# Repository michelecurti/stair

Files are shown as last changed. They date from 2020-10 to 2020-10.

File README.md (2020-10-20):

# stair

Switch on a stair that for every step has a strip led, 
controlled in PWM.
All this to generate a stair "wave effect" for my sister.

## project structure

under hw there is the hardware
under fw there is the firmware

Meh..

## software requirements

I worked on OpenBSD.

For the hardware I used Kicad, for the firmware, vim + Makefile..

The toolchain is arm-none-eabi-gcc-linaro.

The "core" is the STM32 BluePill, some shift registers and some
mosfets..

To debug the board I used the st-link with openocd.

## how to compile

$ cd fw/stair/
$ make

## how to debug

$ make debug

## image

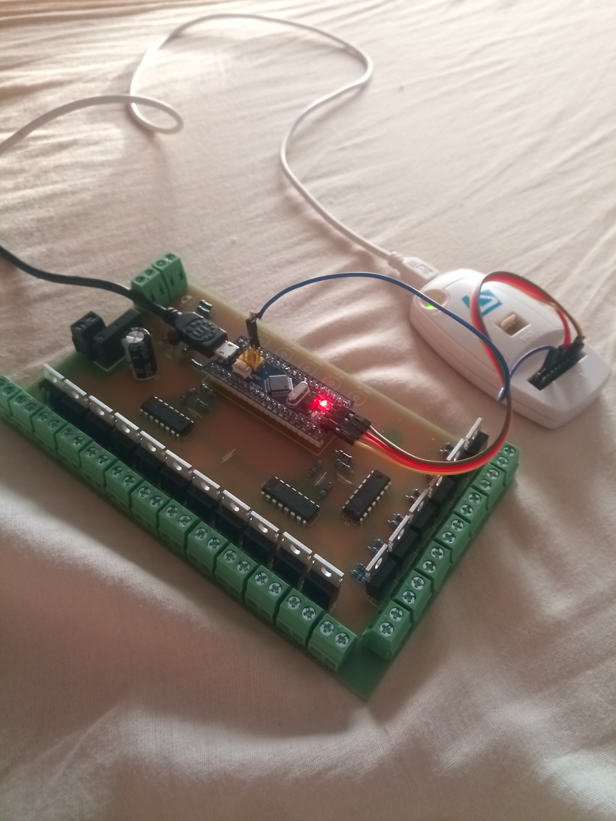
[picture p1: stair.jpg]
the board


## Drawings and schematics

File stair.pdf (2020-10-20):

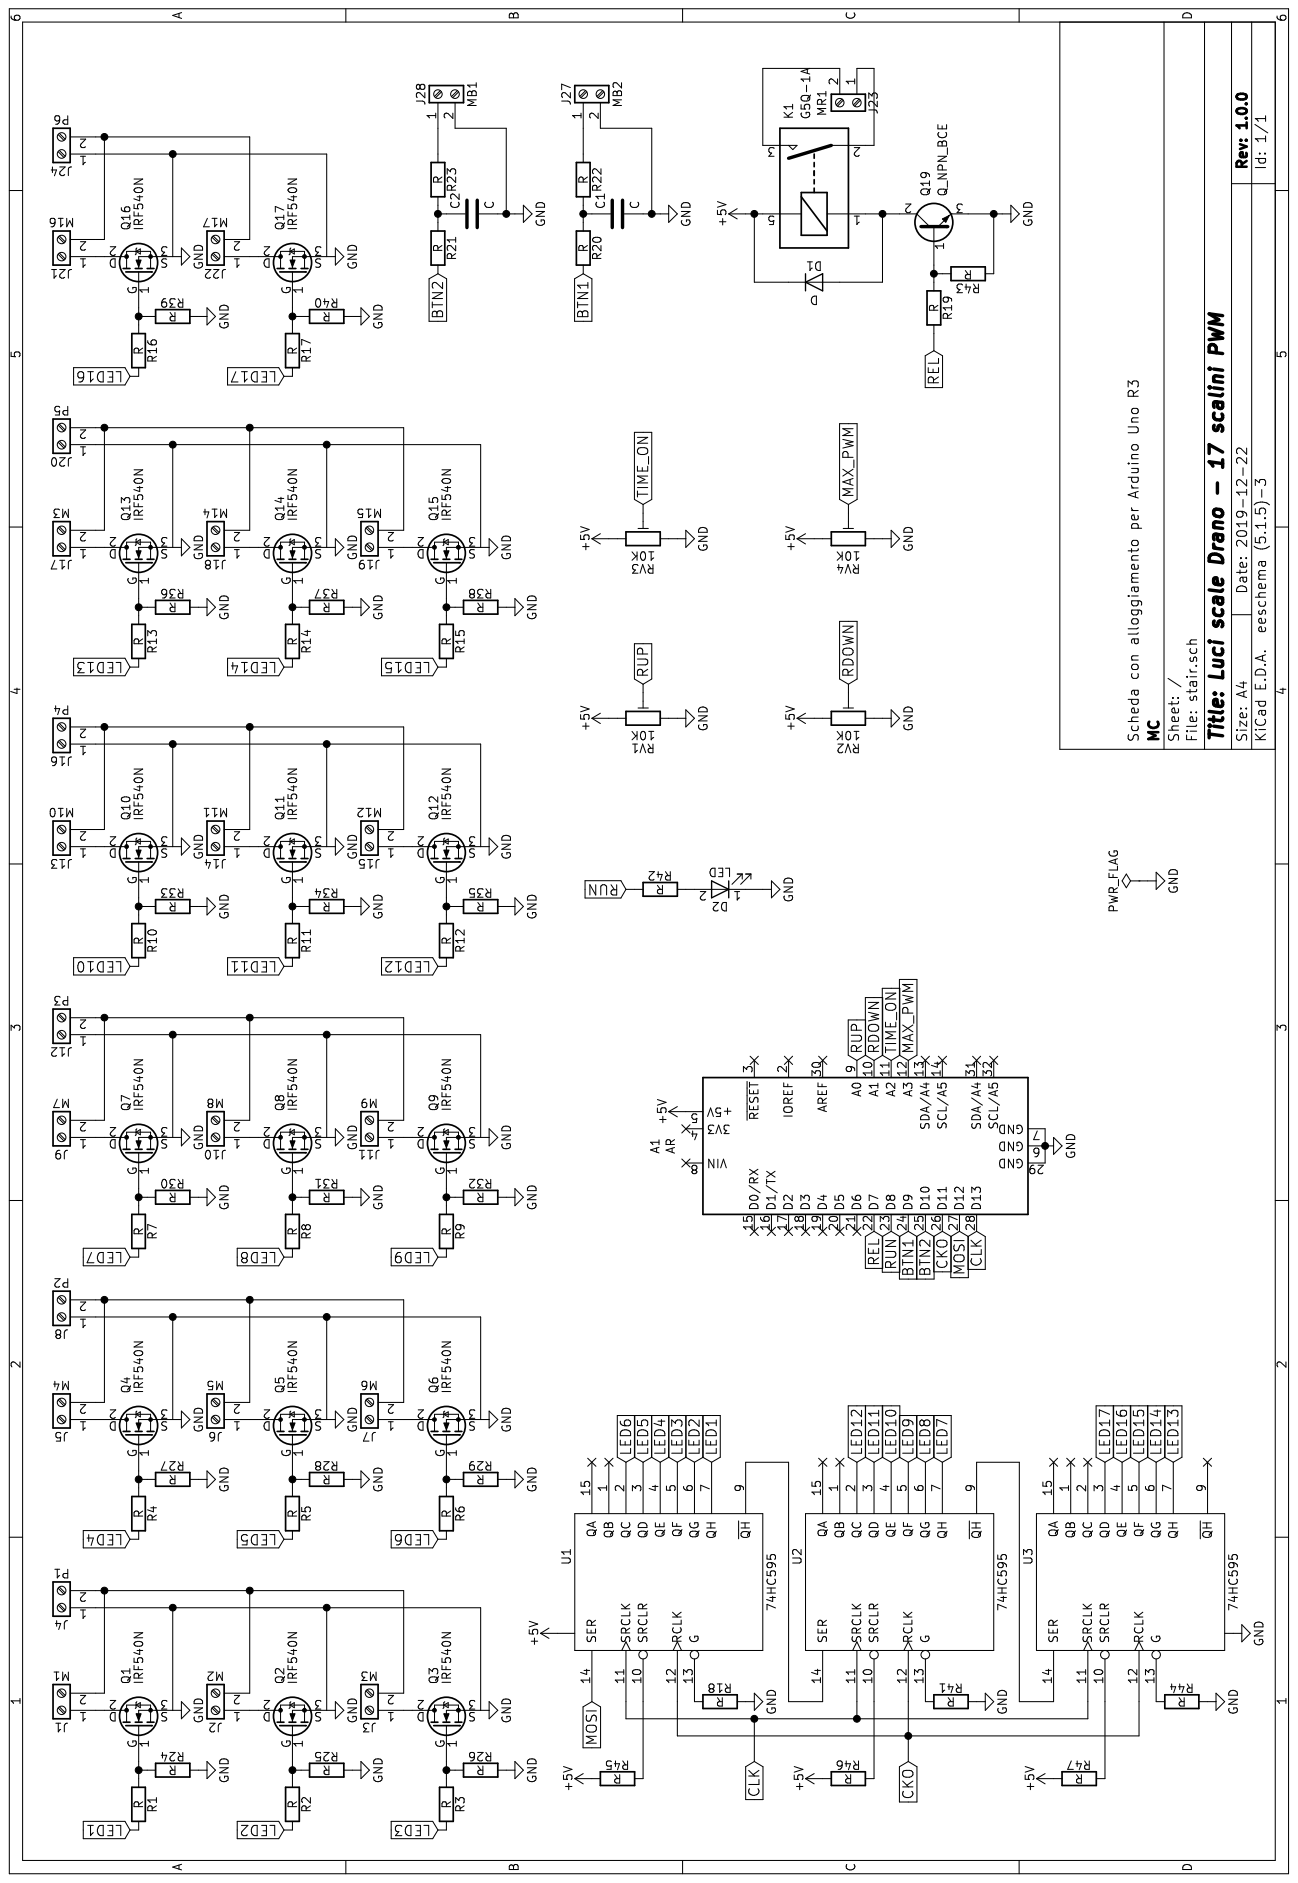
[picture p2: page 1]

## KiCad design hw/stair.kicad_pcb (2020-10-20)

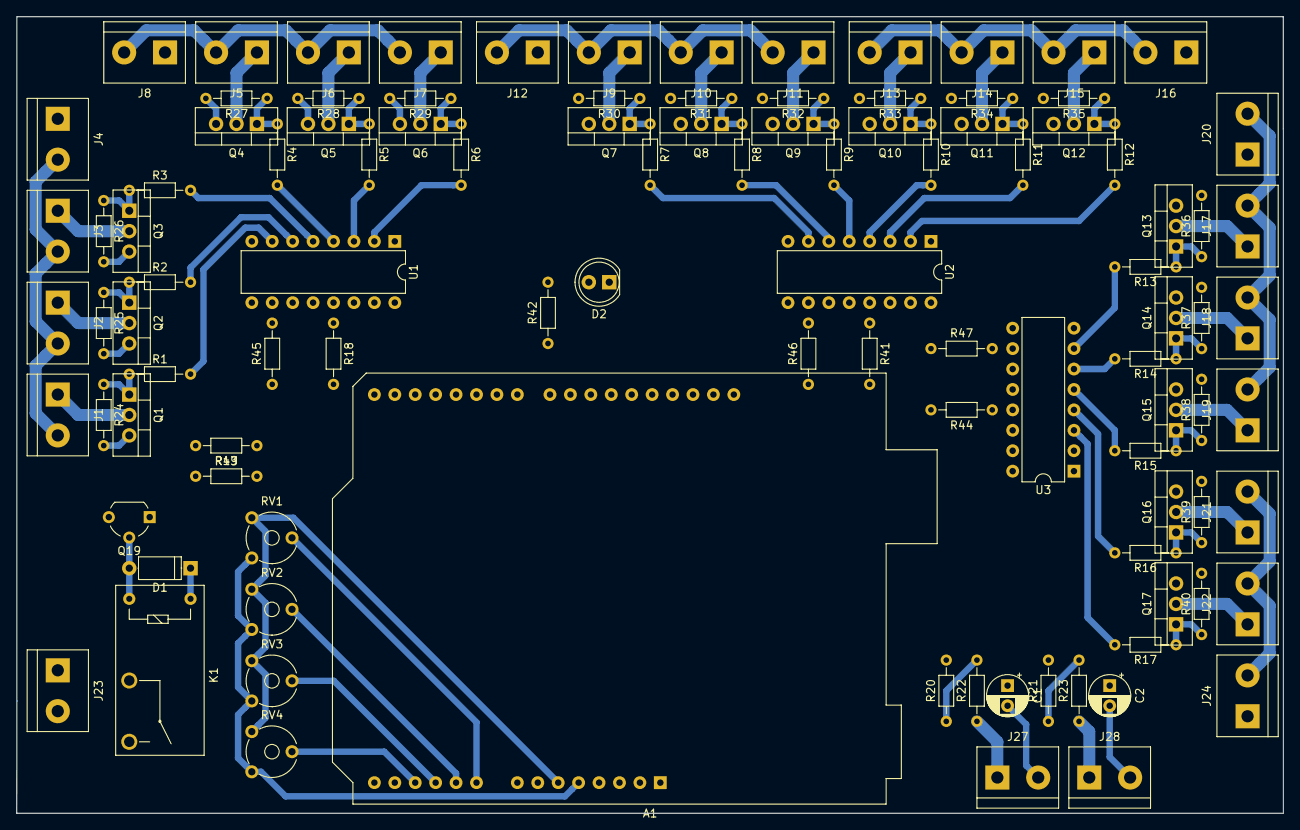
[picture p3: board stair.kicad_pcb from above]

Board: 2 copper layers, 157.5 x 99.1 mm, 104 parts (0 on the bottom side), 87 nets.

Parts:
A1: AR; Arduino_UNO_R3
C1, C2: C; CP_Radial_D5.0mm_P2.50mm
D1: D; D_A-405_P7.62mm_Horizontal
D2: LED; LED_D5.0mm
J1: M1; TerminalBlock_bornier-2_P5.08mm
J2: M2; TerminalBlock_bornier-2_P5.08mm
J3, J17: M3; TerminalBlock_bornier-2_P5.08mm
J4: P1; TerminalBlock_bornier-2_P5.08mm
J5: M4; TerminalBlock_bornier-2_P5.08mm
J6: M5; TerminalBlock_bornier-2_P5.08mm
J7: M6; TerminalBlock_bornier-2_P5.08mm
J8: P2; TerminalBlock_bornier-2_P5.08mm
J9: M7; TerminalBlock_bornier-2_P5.08mm
J10: M8; TerminalBlock_bornier-2_P5.08mm
J11: M9; TerminalBlock_bornier-2_P5.08mm
J12: P3; TerminalBlock_bornier-2_P5.08mm
J13: M10; TerminalBlock_bornier-2_P5.08mm
J14: M11; TerminalBlock_bornier-2_P5.08mm
J15: M12; TerminalBlock_bornier-2_P5.08mm
J16: P4; TerminalBlock_bornier-2_P5.08mm
J18: M14; TerminalBlock_bornier-2_P5.08mm
J19: M15; TerminalBlock_bornier-2_P5.08mm
J20: P5; TerminalBlock_bornier-2_P5.08mm
J21: M16; TerminalBlock_bornier-2_P5.08mm
J22: M17; TerminalBlock_bornier-2_P5.08mm
J23: MR1; TerminalBlock_bornier-2_P5.08mm
J24: P6; TerminalBlock_bornier-2_P5.08mm
J27: MB2; TerminalBlock_bornier-2_P5.08mm
J28: MB1; TerminalBlock_bornier-2_P5.08mm
K1: G5Q-1A; Relay_SPST_OMRON-G5Q
Q1, Q2, Q3, Q4, Q5, Q6, Q7, Q8, Q9, Q10, Q11, Q12, Q13, Q14, Q15, Q16, Q17: IRF540N; TO-220-3_Vertical
Q19: Q_NPN_BCE; TO-92_Wide
R1, R2, R3, R4, R5, R6, R7, R8, R9, R10, R11, R12, R13, R14, R15, R16, R17, R18, R19, R20, R21, R22, R23, R24, R25, R26, R27, R28, R29, R30, R31, R32, R33, R34, R35, R36, R37, R38, R39, R40, R41, R42, R43, R44, R45, R46, R47: R; R_Axial_DIN0204_L3.6mm_D1.6mm_P7.62mm_Horizontal
RV1, RV2, RV3, RV4: 10K; Potentiometer_Trimmer_Piher_PT-6v_Horizontal
U1, U2, U3: 74HC595; DIP-16_W7.62mm

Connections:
+5V: A1.5, D1.1, K1.5, R45.1, R46.1, R47.1, RV1.1, RV2.1, RV3.1, RV4.1, U1.16, U2.16, U3.16
BTN1: A1.24, R20.2
BTN2: A1.25, R21.2
CKO: A1.26, U1.12, U2.12, U3.12
CLK: A1.28, U1.11, U2.11, U3.11
GND: A1.6, A1.7, A1.29, C1.2, C2.2, D2.1, J4.1, J8.1, J12.1, J16.1, J20.1, J24.1, J27.2, J28.2, Q1.3, Q2.3, Q3.3, Q4.3, Q5.3, Q6.3, Q7.3, Q8.3, Q9.3, Q10.3, Q11.3, Q12.3, Q13.3, Q14.3, Q15.3, Q16.3, Q17.3, Q19.3, R18.2, R24.2, R25.2, R26.2, R27.2, R28.2, R29.2, R30.2, R31.2, R32.2, R33.2, R34.2, R35.2, R36.2, R37.2, R38.2, R39.2, R40.2, R41.2, R43.1, R44.2, RV1.3, RV2.3, RV3.3, RV4.3, U1.8, U2.8, U3.8
LED1: R1.2, U1.7
LED2: R2.2, U1.6
LED3: R3.2, U1.5
LED4: R4.2, U1.4
LED5: R5.2, U1.3
LED6: R6.2, U1.2
LED7: R7.2, U2.7
LED8: R8.2, U2.6
LED9: R9.2, U2.5
LED10: R10.2, U2.4
LED11: R11.2, U2.3
LED12: R12.2, U2.2
LED13: R13.2, U3.7
LED14: R14.2, U3.6
LED15: R15.2, U3.5
LED16: R16.2, U3.4
LED17: R17.2, U3.3
MAX_PWM: A1.12, RV4.2
MOSI: A1.27, U1.14
unnamed: C1.1, R20.1, R22.2
unnamed: C2.1, R21.1, R23.2
unnamed: D1.2, K1.1, Q19.2
unnamed: D2.2, R42.2
unnamed: J1.1, Q1.2
unnamed: J1.2, J2.2, J3.2, J4.2
unnamed: J2.1, Q2.2
unnamed: J3.1, Q3.2
unnamed: J5.1, Q4.2
unnamed: J5.2, J6.2, J7.2, J8.2
unnamed: J6.1, Q5.2
unnamed: J7.1, Q6.2
unnamed: J9.1, Q7.2
unnamed: J10.1, Q8.2
unnamed: J9.2, J10.2, J11.2, J12.2
unnamed: J11.1, Q9.2
unnamed: J13.1, Q10.2
unnamed: J13.2, J14.2, J15.2, J16.2
unnamed: J14.1, Q11.2
unnamed: J15.1, Q12.2
unnamed: J17.1, Q13.2
unnamed: J17.2, J18.2, J19.2, J20.2
unnamed: J18.1, Q14.2
unnamed: J19.1, Q15.2
unnamed: J21.1, Q16.2
unnamed: J21.2, J22.2, J24.2
unnamed: J22.1, Q17.2
unnamed: J23.1, K1.2
unnamed: J23.2, K1.3
unnamed: J27.1, R22.1
unnamed: J28.1, R23.1
unnamed: Q1.1, R1.1, R24.1
unnamed: Q2.1, R2.1, R25.1
unnamed: Q3.1, R3.1, R26.1
unnamed: Q4.1, R4.1, R27.1
unnamed: Q5.1, R5.1, R28.1
unnamed: Q6.1, R6.1, R29.1
unnamed: Q7.1, R7.1, R30.1
unnamed: Q8.1, R8.1, R31.1
unnamed: Q9.1, R9.1, R32.1
unnamed: Q10.1, R10.1, R33.1
unnamed: Q11.1, R11.1, R34.1
unnamed: Q12.1, R12.1, R35.1
unnamed: Q13.1, R13.1, R36.1
unnamed: Q14.1, R14.1, R37.1
unnamed: Q15.1, R15.1, R38.1
unnamed: Q16.1, R16.1, R39.1
unnamed: Q17.1, R17.1, R40.1
unnamed: Q19.1, R19.1, R43.2
unnamed: R18.1, U1.13
unnamed: R41.1, U2.13
unnamed: R44.1, U3.13
unnamed: R45.2, U1.10
unnamed: R46.2, U2.10
unnamed: R47.2, U3.10
unnamed: U1.9, U2.14
unnamed: U2.9, U3.14
RDOWN: A1.10, RV2.2
REL: A1.22, R19.2
RUN: A1.23, R42.1
RUP: A1.9, RV1.2
TIME_ON: A1.11, RV3.2

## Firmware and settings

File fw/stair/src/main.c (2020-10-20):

#include "mgmt_hw.h"
#include "mgmt_pwm.h"
#include "app.h"
#include "random.h"

int main(void)
{
	/* intialize hw */
	mgmt_hw_init();

	/* intialize PWM management */
	mgmt_pwm_init();

	/* intialize application */
	app_init();

	for(;;)
	{
		mgmt_hw_fsm();

		/* manage application */
		app_fsm();


		random_fsm();
	}
}

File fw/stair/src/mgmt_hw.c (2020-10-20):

#include <string.h>
#include "stm32f1xx_hal.h"
#include "mgmt_hw.h"
#include "app.h"

#define ADC_CHS		(5)

/* buttons pins */
#define BTNX_GPIO_Port 	GPIOB
#define BTN1_Pin 	GPIO_PIN_0
#define BTN2_Pin 	GPIO_PIN_1
/* output pins */
#define LED_Pin 	GPIO_PIN_13
#define LED_GPIO_Port 	GPIOC
#define LDOUT_Pin 	GPIO_PIN_8
#define LDOUT_GPIO_Port GPIOA
#define RELAY_Pin 	GPIO_PIN_9
#define RELAY_GPIO_Port GPIOB
/* SPI pins*/

static volatile uint32_t ticks;
static uint8_t curr_adc;
static uint32_t adc_vals[ADC_CHS];

static const uint16_t counters[] = 
{
	160, 176, 193, 212, 232, 255, 280, 307, 338, 371, 407, 447, 
	490, 538, 591, 649, 712, 782, 858, 942, 1034, 1135, 1246, 
	1368, 1502, 1649, 1810, 1987, 2182, 2395, 2629, 2886, 3169, 
	3479, 3819, 4192, 4602, 5052, 5546, 6089, 6684, 7338, 8056, 
	8844, 9709, 10658, 11701, 12845, 14101, 15480, 16994, 
	18656, 20481, 22484, 24683, 27097, 29747, 32656, 35850, 
	39356, 43205, 47431, 52070, 57162, 
};

#define MAX_PWM		(sizeof(counters)/sizeof(counters[0]))

static uint8_t irq_cnt;
uint32_t pwms[LEDS_CNT];

static void Error_Handler(void)
{
	for (;;);
}

static void SystemClock_Config(void)
{
	RCC_OscInitTypeDef RCC_OscInitStruct = {0};
	RCC_ClkInitTypeDef RCC_ClkInitStruct = {0};
	RCC_PeriphCLKInitTypeDef PeriphClkInit = {0};

	/* Initializes the CPU, AHB and APB busses clocks */
	RCC_OscInitStruct.OscillatorType = RCC_OSCILLATORTYPE_HSE;
	RCC_OscInitStruct.HSEState = RCC_HSE_ON;
	RCC_OscInitStruct.HSEPredivValue = RCC_HSE_PREDIV_DIV1;
	RCC_OscInitStruct.HSIState = RCC_HSI_ON;
	RCC_OscInitStruct.PLL.PLLState = RCC_PLL_ON;
	RCC_OscInitStruct.PLL.PLLSource = RCC_PLLSOURCE_HSE;
	RCC_OscInitStruct.PLL.PLLMUL = RCC_PLL_MUL8;

	if (HAL_RCC_OscConfig(&RCC_OscInitStruct) != HAL_OK)
	{
		Error_Handler();
	}

	/* Initializes the CPU, AHB and APB busses clocks */
	RCC_ClkInitStruct.ClockType = RCC_CLOCKTYPE_HCLK |
		RCC_CLOCKTYPE_SYSCLK | RCC_CLOCKTYPE_PCLK1 | 
		RCC_CLOCKTYPE_PCLK2;
	RCC_ClkInitStruct.SYSCLKSource = RCC_SYSCLKSOURCE_PLLCLK;
	RCC_ClkInitStruct.AHBCLKDivider = RCC_SYSCLK_DIV1;
	RCC_ClkInitStruct.APB1CLKDivider = RCC_HCLK_DIV2;
	RCC_ClkInitStruct.APB2CLKDivider = RCC_HCLK_DIV1;

	if (HAL_RCC_ClockConfig(&RCC_ClkInitStruct, 
				FLASH_LATENCY_2) != HAL_OK)
	{
		Error_Handler();
	}

	PeriphClkInit.PeriphClockSelection = RCC_PERIPHCLK_ADC;
	PeriphClkInit.AdcClockSelection = RCC_ADCPCLK2_DIV4;

	if (HAL_RCCEx_PeriphCLKConfig(&PeriphClkInit) != HAL_OK)
	{
		Error_Handler();
	}
}

static void MX_SPI2_Init(void)
{
	/* enable clock */
	__HAL_RCC_SPI2_CLK_ENABLE();

	/* disable SPI2 */
	SPI2->CR1 &= SPI_CR1_SPE;

	/* set prescaler */
	SPI2->CR1 |= SPI_BAUDRATEPRESCALER_4;

	/* master mode */
	SPI2->CR1 |= SPI_MODE_MASTER;

	/* do not use slave select */
	SPI2->CR1 |= SPI_CR1_SSM;
	//SPI2->CR1 &= ~SPI_CR1_SSI;

	/* enable SPI2 */
	SPI2->CR1 |= SPI_CR1_SPE;
}

static void MX_GPIO_Init(void)
{
	GPIO_InitTypeDef GPIO_InitStruct = { 0 };

	/* GPIO Ports Clock Enable */
	__HAL_RCC_GPIOA_CLK_ENABLE();
	__HAL_RCC_GPIOB_CLK_ENABLE();
	__HAL_RCC_GPIOC_CLK_ENABLE();
	__HAL_RCC_GPIOD_CLK_ENABLE();

	/*Configure GPIO pin Output Level */
	HAL_GPIO_WritePin(LED_GPIO_Port, LED_Pin, GPIO_PIN_SET);

	/*Configure GPIO pin Output Level */
	HAL_GPIO_WritePin(LDOUT_GPIO_Port, LDOUT_Pin, GPIO_PIN_RESET);

	/*Configure GPIO pin : LED_Pin */
	GPIO_InitStruct.Pin = LED_Pin;
	GPIO_InitStruct.Mode = GPIO_MODE_OUTPUT_PP;
	GPIO_InitStruct.Pull = GPIO_NOPULL;
	GPIO_InitStruct.Speed = GPIO_SPEED_FREQ_LOW;
	HAL_GPIO_Init(LED_GPIO_Port, &GPIO_InitStruct);

	/*Configure GPIO pin : RELAY_Pin */
	GPIO_InitStruct.Pin = RELAY_Pin;
	GPIO_InitStruct.Mode = GPIO_MODE_OUTPUT_PP;
	GPIO_InitStruct.Pull = GPIO_NOPULL;
	GPIO_InitStruct.Speed = GPIO_SPEED_FREQ_LOW;
	HAL_GPIO_Init(RELAY_GPIO_Port, &GPIO_InitStruct);

	/*Configure GPIO pin : LDOUT_Pin  */
	GPIO_InitStruct.Pin = LDOUT_Pin;
	GPIO_InitStruct.Mode = GPIO_MODE_OUTPUT_PP;
	GPIO_InitStruct.Pull = GPIO_NOPULL;
	GPIO_InitStruct.Speed = GPIO_SPEED_FREQ_LOW;
	HAL_GPIO_Init(LDOUT_GPIO_Port, &GPIO_InitStruct);

	/*Configure GPIO pins : BTN1_Pin BTN2_Pin */
	GPIO_InitStruct.Pin = BTN1_Pin | BTN2_Pin;
	GPIO_InitStruct.Mode = GPIO_MODE_INPUT;
	GPIO_InitStruct.Pull = GPIO_PULLUP;
	HAL_GPIO_Init(BTNX_GPIO_Port, &GPIO_InitStruct);
	
	/* configure ADC pins */
	memset(&GPIO_InitStruct, 0, sizeof(GPIO_InitStruct));
	GPIO_InitStruct.Pin = GPIO_PIN_0 | GPIO_PIN_1 | GPIO_PIN_2 |
		GPIO_PIN_3 | GPIO_PIN_4;
	GPIO_InitStruct.Mode = GPIO_MODE_ANALOG;
	GPIOA->CRL &= 0xFFFFFC00;
	//HAL_GPIO_Init(GPIOA, &GPIO_InitStruct);

	/* configure SPI pins */
	GPIO_InitStruct.Pin = GPIO_PIN_13 | GPIO_PIN_15;
	GPIO_InitStruct.Mode = GPIO_MODE_AF_PP;
	GPIO_InitStruct.Speed = GPIO_SPEED_FREQ_HIGH;
	HAL_GPIO_Init(GPIOB, &GPIO_InitStruct);
}

static void MX_ADC1_Init(void)
{
	__HAL_RCC_ADC1_CLK_ENABLE();

	ADC1->CR2 |= ADC_CR2_ADON;
	while((ADC1->CR2 | ADC_CR2_ADON) == 0);
	ADC1->CR2 |= ADC_CR2_EXTSEL;

	ADC1->SMPR1 = 0x7FFFFFFF;
	ADC1->SMPR2 = 0xCFFFFFFF;
}

static void pwm_timer_init(void)
{
	/* enable clock */
	__HAL_RCC_TIM4_CLK_ENABLE();

	/* set prescaler */
	TIM4->PSC = 0;

	/* schedule first timer interrupt */
	TIM4->ARR = 0xFFFE;

	/* enable counter */
	TIM4->CR1 |= TIM_CR1_CEN;

	/* enable counter interrupt */
	TIM4->DIER |= TIM_DIER_UIE;

	/* enable TIM4 interrupt */
	NVIC_EnableIRQ(TIM4_IRQn);
}

void SysTick_Handler (void)
{
	HAL_IncTick();
}

void mgmt_hw_init(void)
{
	SystemClock_Config();
	//SystickInit(APP_TICK_FREQ);
	HAL_Init();
	MX_GPIO_Init();
	MX_SPI2_Init();
	MX_ADC1_Init();
	pwm_timer_init();
}

void mgmt_hw_fsm(void)
{
	static uint32_t old;
	uint32_t tick;

	tick = HAL_GetTick() / 50;

	if (tick != old)
	{
		old = tick;

		adc_vals[curr_adc] = (adc_vals[curr_adc] + ADC1->DR) / 2;

		if (++curr_adc >= ADC_CHS)
		{
			curr_adc = 0;
		}

		ADC1->SQR3 = (curr_adc << (0 * 5));
		ADC1->CR2 |= ADC_CR2_SWSTART;
		ADC1->CR2 &= ~ADC_CR2_SWSTART;
	}
}

/* 
 * macro to set the PWM PIN output
 * p is the PWM index
 * b is the byte in tx buffer (the shift register index)
 * i is the bit index of the byte
 */
#define SET_OUT(p, b, i)		\
	if (irq_cnt < pwms[(p)]) 		\
	 buff[(b)] |= (1 << (i)); else\
	 buff[(b)] &= ~(1 << (i))
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
